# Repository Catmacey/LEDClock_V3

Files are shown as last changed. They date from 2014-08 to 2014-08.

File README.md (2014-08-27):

Circular LED Clock
==================

This is an digital LED "Analogue" clock using 60 dicrete LEDs in a circular pattern.
It's an old project built on two single sided boards. The boards are designed for easy home fabrication using the toner transfer technique.  The CPU board uses all DIP parts, the display board uses surface mount LEDs in 1206 package.

The MCU is a 18f2525 with a Maxim MAX6956 driving the LEDs and a Maxim DS1307 keeping time.

[More information is available on my blog.](http://catmacey.wordpress.com/projects/led-clock-project/led-clock-project-details/)

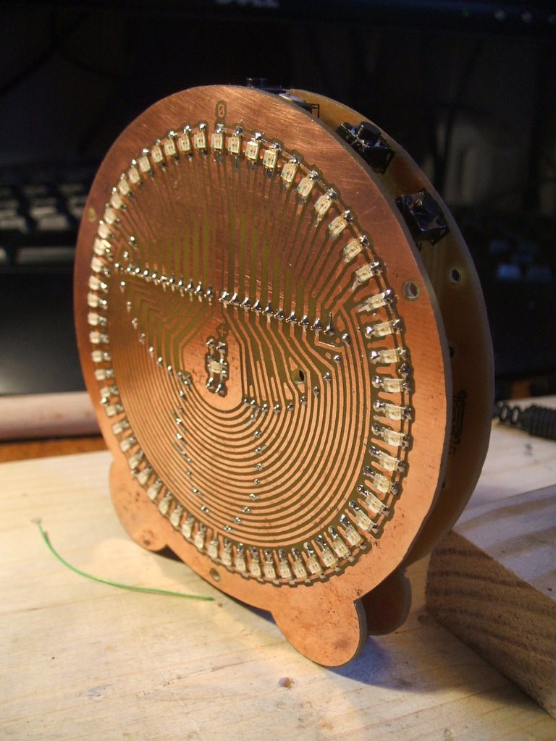
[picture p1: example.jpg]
My image


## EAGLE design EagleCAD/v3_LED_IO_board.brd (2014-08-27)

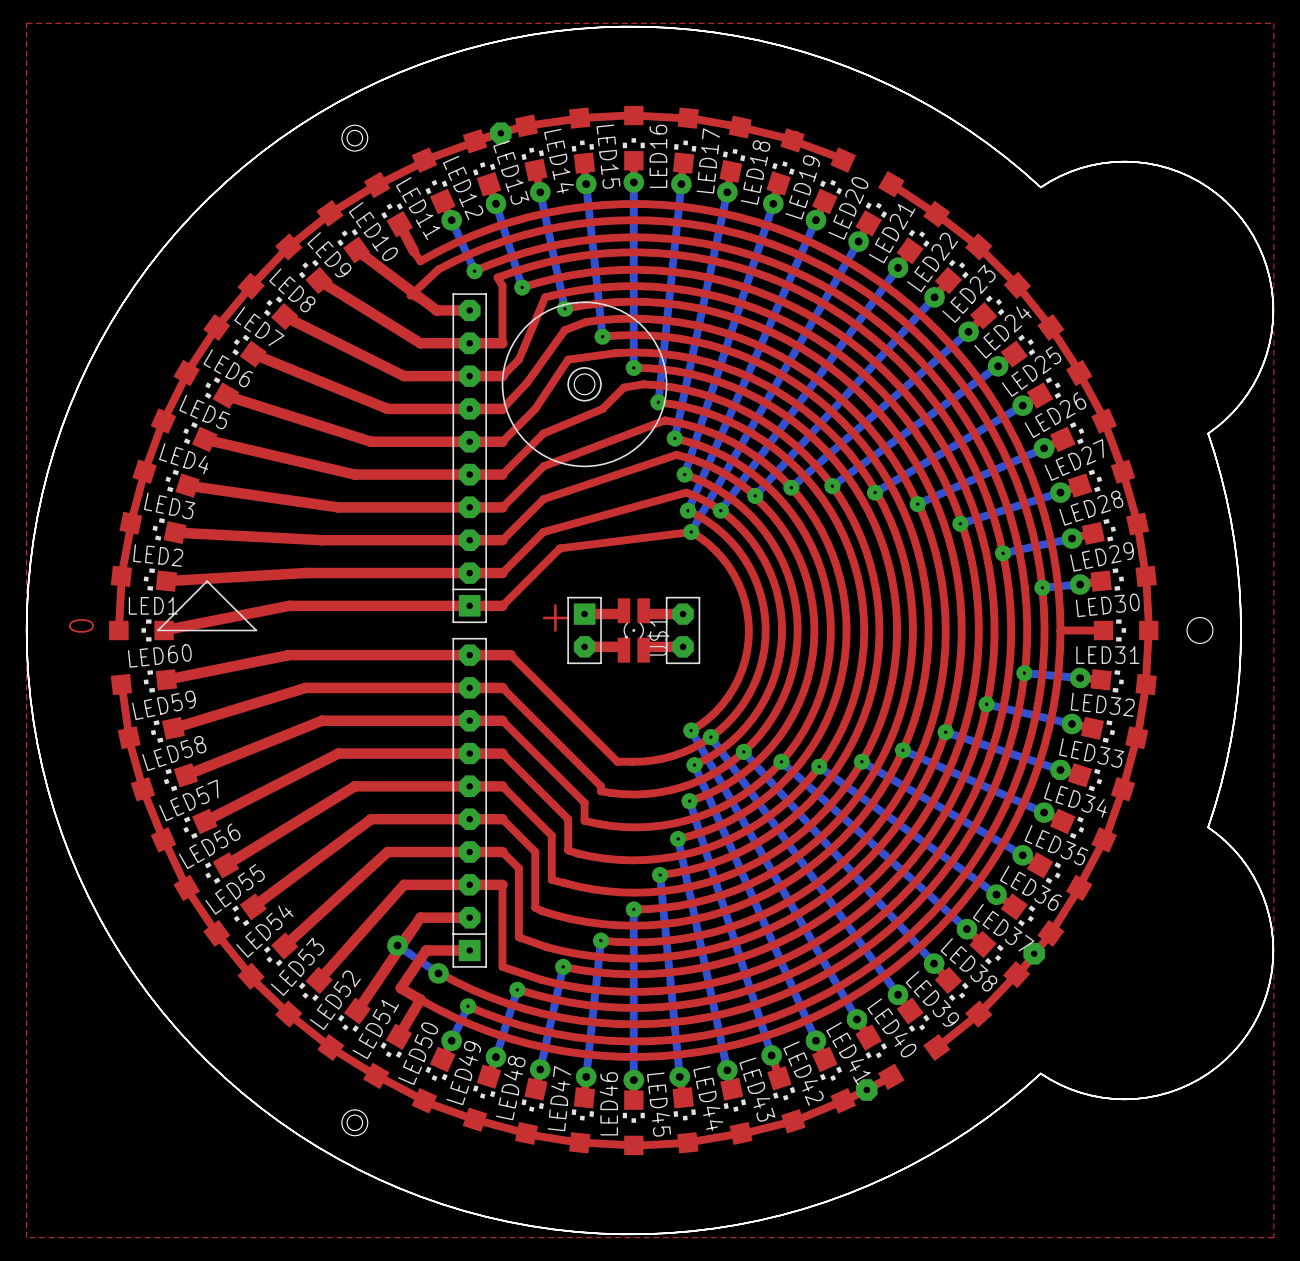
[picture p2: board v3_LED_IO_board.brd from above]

Board: 2 copper layers, 96.5 x 93.5 mm, 62 parts (0 on the bottom side), 27 nets.

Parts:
LED1, LED2, LED3, LED4, LED5, LED6, LED7, LED8, LED9, LED10, LED11, LED12, LED13, LED14, LED15, LED16, LED17, LED18, LED19, LED20, LED21, LED22, LED23, LED24, LED25, LED26, LED27, LED28, LED29, LED30, LED31, LED32, LED33, LED34, LED35, LED36, LED37, LED38, LED39, LED40, LED41, LED42, LED43, LED44, LED45, LED46, LED47, LED48, LED49, LED50, LED51, LED52, LED53, LED54, LED55, LED56, LED57, LED58, LED59, LED60: CHIPLED_1206
U$1: RGBLED; 1206_RGBLED
U$2: LEDCLOCK_FRONT

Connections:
+5V: U$1.A, U$2.+5V
LED6: LED6.C, LED26.C, LED46.C, U$2.JL6
unnamed: LED9.C, LED29.C, LED49.C, U$2.JL9
unnamed: LED1.A, LED2.A, LED3.A, LED4.A, LED5.A, LED6.A, LED7.A, LED8.A, LED9.A, LED10.A, LED11.A, LED12.A, LED13.A, LED14.A, LED15.A, LED16.A, LED17.A, LED18.A, LED19.A, LED20.A, U$2.BANK1
unnamed: LED1.C, LED21.C, LED41.C, U$2.JL1
unnamed: LED2.C, LED22.C, LED42.C, U$2.JL2
unnamed: LED3.C, LED23.C, LED43.C, U$2.JL3
unnamed: LED4.C, LED24.C, LED44.C, U$2.JL4
unnamed: LED5.C, LED25.C, LED45.C, U$2.JL5
unnamed: U$1.R, U$2.JIN1
unnamed: LED7.C, LED27.C, LED47.C, U$2.JL7
unnamed: LED19.C, LED39.C, LED59.C, U$2.JL19
unnamed: LED10.C, LED30.C, LED50.C, U$2.JL10
unnamed: U$1.B, U$2.JIN2
unnamed: U$1.G, U$2.JIN3
unnamed: LED8.C, LED28.C, LED48.C, U$2.JL8
unnamed: LED21.A, LED22.A, LED23.A, LED24.A, LED25.A, LED26.A, LED27.A, LED28.A, LED29.A, LED30.A, LED31.A, LED32.A, LED33.A, LED34.A, LED35.A, LED36.A, LED37.A, LED38.A, LED39.A, LED40.A, U$2.BANK2
unnamed: LED11.C, LED31.C, LED51.C, U$2.JL11
unnamed: LED12.C, LED32.C, LED52.C, U$2.JL12
unnamed: LED13.C, LED33.C, LED53.C, U$2.JL13
unnamed: LED14.C, LED34.C, LED54.C, U$2.JL14
unnamed: LED15.C, LED35.C, LED55.C, U$2.JL15
unnamed: LED17.C, LED37.C, LED57.C, U$2.JL17
unnamed: LED18.C, LED38.C, LED58.C, U$2.JL18
unnamed: LED20.C, LED40.C, LED60.C, U$2.JL20
unnamed: LED41.A, LED42.A, LED43.A, LED44.A, LED45.A, LED46.A, LED47.A, LED48.A, LED49.A, LED50.A, LED51.A, LED52.A, LED53.A, LED54.A, LED55.A, LED56.A, LED57.A, LED58.A, LED59.A, LED60.A, U$2.BANK3
unnamed: LED16.C, LED36.C, LED56.C, U$2.JL16

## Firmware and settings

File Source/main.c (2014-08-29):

/*
////////////////
	LED	analog clock
////////////////
*/

/*
////////////////
	Work log

*	Add some LEDs on portA to indicate status.
	Set Time : Set Alarm : Alarm active
!	Done : 19 Apr 07, also made time set & alarm set active only on delayed hold down.

!	Sort out reading/writing to the RTC.
	Might need to hard wire this to make I2C work ok.
	Also might need to slow down I2C, which might effect over all display
!	Done (most of) 22 Apr 07, reads for RTC, but doesn't set it yet. i2c at 100khz, seems ok.

!	Need to sort out writing time to RTC (dec2bcd)
!	Also need to sort out odd slownes of blinking for mins.
!	Compare alarm to current time.
!	Buzz or something for 10 mins
!	Just worked out why was having probs with RTC & GPIO on i2c bus
	Was due to the interrupt routine interrupting a main() i2c access
	Rememeber to either only i2c from isr or disable ints whilst i2c's in main()
!	Need to work out some sort of snooze mode for the alarm (hit any button other than alarm set)
	and wire up some sort of buzzer
!	Buzzer driven using PWM out on RB3.
!	Snooze and alarm to be working ok.  Alarm sounds for 25 mins with a 5 min snooze capability
!	Added LDR to RA0 to change global current of GPIO dependant on ambient light.
*	Want to re-write convertTime2light() to allow for...
	!	More realistic Hour display eg, use the LEDs inbetween the hours points to show like a real analog clock
	!	Simple animations on certain events.  Eg. every hours chase a dot around the clock or similar.
!	Buzzer swapped for active type, no need for pwm out still on rb3
!	Need to re-write main text (if) in alarm_test()
!	Indicator LED swapped for RGB LED to create multi colors
	PWM of RGB LED provided by using RA1
!	Animation capability added using effect_run() and associated funcs
!	MAX6956 individual LED current now used to balance the red/blue intensity.
!	PWM on RC0,1,2 now used to dim LEDs rather than global current of MAX6956

!	18 Nov 07
	Rewrite to use LAT for output rather than PORT
////////////////
*/


#include <p18cxxx.h>
#include <delays.h>
#include <usart.h>
#include <i2c.h>
#include <stdio.h>
#include <timers.h>
#include <adc.h>
#include <portb.h>
#pragma	config WDT = OFF

#define _SIM

#define	LoByte(i)	(	(unsigned	char)	i	)
#define	HiByte(i)	(	(unsigned	char)	(	((unsigned int)	i) >>	8) )
#define	MidByte(i)	(	(unsigned	char)	(	((unsigned short long) i)	>> 16) )
#define	TopByte(i)	(	(unsigned	char)	(	((unsigned long) i)	>> 24) )

//PortA
//outputs
#define	LDR						PORTAbits.RA0	//porta.0
#define	LED_PWM			LATAbits.LATA1	//porta.1
#define	ALARMOUT			LATAbits.LATA2	//porta.2
#define	LED_ALERT			LATAbits.LATA4	//active low (Green)
#define	LED_ALARM			LATAbits.LATA5	//active low (Red)
#define	LED_AMPM			LATAbits.LATA3	//active low (Blue)

//Port B
//inputs
#define	rtcin					PORTBbits.RB0	//Pulse input for RTC
#define	btn0					PORTBbits.RB1	//Alarm on/off/set
#define	btn1					PORTBbits.RB2	//Time set/run
#define	btn2					PORTBbits.RB3	//Snooze/sleep
#define	btn3					PORTBbits.RB4	//min inc
#define	btn4					PORTBbits.RB5	//hour
//outputs
#define	RB6	PORTBbits.RB6
#define	RB7	PORTBbits.RB7

//Masks for buttons
#define	BTN_ALARMSET		0b00100000
#define	BTN_TIMESET			0b00010000
#define	BTN_SNOOZE			0b00001000
#define	BTN_HOURADV		0b00000100
#define	BTN_MINADV			0b00000010
#define	DBOUNCEMASK		0b00111110 //only bother to count these pins in dbouncing
#define 	DLY_LONG				70	// A long delay for detecting a held down button (time and alarm set)
#define 	DLY_LONG_RST		75	// Ensures no repeat	
#define 	DLY_SHORT				33 	// A short delay for detecting a held down button (mins + hour advance)
#define	DLY_SHORT_RST	30	// Makes a nice repeat rate for advance
#define	LIGHTMAX				15	//max value for gbl_light
#define	LIGHTCEIL				512 //1024 - 512 //When light levels are below this level just use pwm of 0
#define	LIGHTDIV					(LIGHTCEIL / (LIGHTMAX+1))	//(1024 - 512) / 15

//Port C
#define	RC0		PORTCbits.RC0	//sector0 sel
#define	RC1		PORTCbits.RC1	//sector1 sel
#define	RC2		PORTCbits.RC2	//sector2 sel
#define	SCL		PORTCbits.RC3	//I2C clock,	PORTC	pin	3
#define	SDA		PORTCbits.RC4	//I2C data
#define	RC5		PORTCbits.RC5	
#define	TX		PORTCbits.RC6
#define	RX		PORTCbits.RC7

#define	MAX6956ADDR 0x80 //address of 6956 GPIO
#define	RTCADDR 0b11010000 //address of DS1307 RTC
#define	RTCLEN 3 //number of bytes to read from RTC (zero based)
#define	ALARMLIMIT 30 //max time for alarm
#define	SNOOZELIMIT 9 //max time for alarm

unsigned char gbl_ledBuffer_written; //used to flag that we have new data, not allowed to write until unset
unsigned char gbl_ledBuffer_bank; //[0|1] bank we are currently writing to. (isr reads other)
unsigned char	gbl_ledBuffer[2][3][3]; //gbl_ledBuffer :2 banks of 3 sectors of 3 bytes representing status of the	60 leds	(last	4	bits of	byte [x][3]	unused)
//unsigned short long gbl_effect.buffer[3]; //3 sectors of 24bits representing effects display(last 4 bits of byte [x][3]	unused)
struct{
		unsigned char sector; 	// Store which bank the effect is using. Or sometimes just a spare
		unsigned char ctr;			// Counter for effects so they can top themselves
		unsigned char mode;		// Effects mode
		unsigned char temp;		// Temp...
		union buffer_tmp{
			unsigned short long full;
			struct{
				unsigned char low;
				unsigned char mid;
				unsigned char high;
			};
		} buffer[3];
} gbl_effect;

rom	char sectorSelBits[] = {0x00,0x01,0x02};//Bank selects. AND this bits of port c (LATC)
rom	char sectorAddr[]	=	{0x4c,0x54,0x5c	};//addresses of GPOI ports 12-19,20-27,28-31

unsigned char	gbl_sector;						//used by isr to keep track of current sector
unsigned char	gbl_blinkOff_Min;			//should we blink the mins at all?
unsigned char	gbl_blinkStatus_Min;		//display mins (blink)
unsigned char gbl_blinkStatus_Sec;		//display seconds (blink), used to make seconds a quick pulse
unsigned char	gbl_display_secs;			//display seconds
unsigned char gbl_timeSelect;				//Set [0=time|1=alarm]
unsigned char	gbl_bRun;						//[run/set] time
unsigned char gbl_bTimeChanged;		//Set [1=time has changed]
unsigned char gbl_bAlarmSet;				//Set [1=alarm is armed]
unsigned char gbl_bAlarmSnd;				//Set [1=alarm is currently sounding!]
unsigned char gbl_bSnooze;					//Set [1=we are snoozing!]
unsigned char gbl_bPm;							//Set [0=am,1=pm]
unsigned char gbl_blinky;						//Used as a simple counter for blinking seconds and alarm
unsigned char	gbl_light;							//Light lever 0 - 24
unsigned char	gbl_PartialHour;				//Bool : 1 = show hours as partial, 0 = show hours as whole numbers

//Config words for GPIO {length (hex), start address (hex), data (hex)}
rom	char gpio_start_0[]			= {0x02,0x04,0b01000001};		//config byte
rom	char gpio_start_1[]			= {0x2,0x02,0x00001111};		//global current control : Unnecesary now we are using per seg current to balance brightness
rom	char gpio_start_2[]			= {0x08,0x09,0x00,0x00,0x00,0x00,0x00,0x00,0x00};	//config all ports as LED const cur	driver
//Current per segment
rom	char gpio_start_3[]			= {0x0c,0x16,0xf6,0xff,0x6f,0xff,0xff,0xf6,0xff,0x6f,0xff,0xff};
rom	char gpio_testModeOn[] 	= {0x02,0x07,0x01};
rom	char gpio_testModeOff[]	= {0x02,0x07,0x00};

unsigned char	gbl_temp[10];	//used as a temp buffer for communication

//Debounce stuff
#define	DBOUNCE_LEN 12//length of debounce buffer
unsigned char gbl_dbounce_buff[DBOUNCE_LEN];	//ring buffer for debouncing
unsigned char gbl_dbounce_idx;	//current byte to write
unsigned char gbl_status;	//current byte to write

//time holder : it's the same order as the RTC
union time_t{
	unsigned char arr[RTCLEN];
	struct{
		unsigned char second;
		unsigned char minute;
		unsigned char hour;
/*
		unsigned char day;
		unsigned char date;
		unsigned char month;
		unsigned char year;
*/
	};
} times[3];
//Indexes of time holders
#define	TNOW 0 //now
#define	TALMON 1 //Alarm on
#define	TSNOOZE 2 //Alarm sleep

#define	SEC		0 //position in time_t.arr
#define	MIN		1 //position in time_t.arr
#define	HOUR	2 //position in time_t.arr

//func prototypes
void boot_up(	void );
void gpio_init(void);
void rtc_init(void);
void convertTime2light();
void effect_run();
void set_dbounce();
void time_inc(union time_t *theTime, unsigned char part, unsigned char amount);
void effect_next();
void gpio_readConfig(unsigned char addr, unsigned char length);
signed char	I2C_sendRomStr(unsigned	char addr, unsigned	rom	char *wrptr	);
signed char	gpio_drawSector(unsigned char sector);
signed char	readRTC();
signed char	setRTC();
signed char	alarm_storeTime();
unsigned char	time_dec(unsigned	char part,unsigned char	amount);
unsigned char get_dbounce();
unsigned char bcd2dec(unsigned char bcd);
unsigned char dec2bcd(unsigned char dec);
unsigned int timeDiff(unsigned char timeIdx1, unsigned char timeIdx2);


void timer_isr (void);
#pragma	code low_vector=0x18
void
low_interrupt	(void){
	_asm GOTO	timer_isr	_endasm
}
#pragma	code

#pragma	interruptlow timer_isr
void timer_isr (void){
	//int
	signed char rtn;
	unsigned char tmp;
	
	if(INTCONbits.INT0IF){
		//RTC seconds ticker
		time_inc(&times[TNOW],SEC,1);
		gbl_blinkStatus_Min = !gbl_blinkStatus_Min;
		gbl_bTimeChanged = 1;//flag that time has changed (alarm test uses this)
		INTCONbits.INT0IF = 0;	//reset int
	}

	tmp = gbl_sector;
	
	if(INTCONbits.TMR0IF){
		//Timer 0 int
		
		//PWM of Indicator LEDS. 6bit period (63), max duty of 16
		if(
			((gbl_blinky & 0b00111111) <= gbl_light)
			||
			gbl_bAlarmSnd
		){
			//ON
			//pwm for center led
			LED_PWM = 1;
		}else{
			//OFF
			LED_PWM = 0;
		}

		//PWM of Sectors. 5bit period (31), max duty of 16
		if(
			((gbl_blinky & 0b00011111) <= gbl_light)
			||
			gbl_bAlarmSnd
		){
			//ON
			//pwm for sectors already set by code below
		}else{
			//OFF
			LATC &= 0b11111000;		
		}

		//de-Bounce inputs (portB). Every 32th int
		if((gbl_blinky & (unsigned char) 0b00000111) == (unsigned char) 0b00000111){
			set_dbounce();
		}
		
		//Write to MAX6956
		if((gbl_blinky & (unsigned char) 0b00011111) == (unsigned char) 0b00011111){
			//every 16th int			
			if(gbl_sector > (unsigned char) 2){
				gbl_sector = 0;
				if(gbl_ledBuffer_written){
					//new data on other buffer so toggle it, but only after all 3 sectors have been displayed
					if(gbl_ledBuffer_bank) gbl_ledBuffer_bank = 0;
					else gbl_ledBuffer_bank = 1;
					gbl_ledBuffer_written = 0;//flag main() that it can write to buffer again.
				}//if
			}//if
	
			rtn = gpio_drawSector(gbl_sector);	// Write to the GPIO
			if(rtn) fprintf	(_H_USART, "(%#i) ",rtn); //error writing
			//sector counter
			gbl_sector++;
		}
		gbl_blinky++;
		INTCONbits.TMR0IF	=	0;	//reset	timer 0
	}
}//func

void alarm_updateOff(){
	//copies alarm time to alarm off time + 15 mins
	fprintf(_H_USART, "\r\nalarm_updateOff(");
	times[TSNOOZE] = times[TALMON]; //snooze defaults to alarm on
	fprintf(_H_USART, "Snooze %.2u:%.2u:%.2u)\r\n",times[TSNOOZE].hour,times[TSNOOZE].minute,0);
}

void alarm_setSnooze(){
	//set snooze time times[TSNOOZE] and flag
	fprintf(_H_USART, "\r\nalarm_setSnooze(");
	if(gbl_bAlarmSnd){
		//set snooze time
		gbl_bSnooze = 1;
		times[TSNOOZE] = times[TNOW];
		time_inc(&times[TSNOOZE],MIN,SNOOZELIMIT);
		fprintf(_H_USART, "%.2u:%.2u:%.2u",times[TSNOOZE].hour,times[TSNOOZE].minute,times[TSNOOZE].second);
	}else{
		//not alarm sounding, no point
		gbl_bSnooze = 0;
		fprintf(_H_USART, "nada");
	}
	fprintf(_H_USART, ")\r\n");
}

/*
	calculates the difference between time 1 and time 2 (index's supplied)
	timeIdx1 = now, timeIdx2 = then
	Returns result in mins always positive cos could be tomorrow (unsigned int) 
*/
unsigned int timeDiff(unsigned char timeIdx1, unsigned char timeIdx2){
	unsigned int timeDiff;
	unsigned int timeNow;
	unsigned int timeThen;
	timeNow 		= ((unsigned int) times[timeIdx1].hour * 60) + times[timeIdx1].minute; //minutes
	timeThen 	= ((unsigned int) times[timeIdx2].hour * 60) + times[timeIdx2].minute; //minutes
	if(timeNow <= timeThen){
		//then is in the future within the same day.
		timeDiff = timeThen - timeNow;
	}else{
		//then is in the past, so could be tommorrow.
		timeDiff = timeThen + 1440 - timeNow;
	}//if
	//fprintf	(_H_USART, "Now[%#.1u] %#.2u:%#.2u (%u), then[%#.1u] %#.2u:%#.2u (%u), diff:%#.4u\r\n", timeIdx1, times[timeIdx1].hour, times[timeIdx1].minute, timeNow, timeIdx2, times[timeIdx2].hour, times[timeIdx2].minute, timeThen, timeDiff);
	return timeDiff;
}


void alarm_test(){
	//checks current time against alarm
	/*
	fprintf	(_H_USART, "\r\nTest alarm. %b\r\n",gbl_bAlarmSet);
	fprintf	(_H_USART, "Time : %#.2u:%#.2u\r\n", times[TNOW].hour,times[TNOW].minute);
	fprintf	(_H_USART, "Alon : %#.2u:%#.2u\r\n", times[TALMON].hour,times[TALMON].minute);
	fprintf	(_H_USART, "Snz : %#.2u:%#.2u\r\n", times[TSNOOZE].hour,times[TSNOOZE].minute);
	*/
	if(
		gbl_bAlarmSet
		&
		timeDiff((unsigned char) TALMON,(unsigned char) TNOW) < (unsigned char) ALARMLIMIT //diff between now and alarm tigger <= ALARMLIMIT
	){
		gbl_bAlarmSnd = 1; //Alarm sounding (or at least it might be)
		if(timeDiff((unsigned char) TSNOOZE, (unsigned char) TNOW) < (unsigned char) SNOOZELIMIT){
			//within the alarm time and not snoozing, sound alarm
			fprintf	(_H_USART, "\r\nAlarm!\r\n");
			if(times[TNOW].second & 0b00000001) {
				ALARMOUT = 1;  //sound alarm
			}else{
				ALARMOUT = 0;  //un-sound alarm
			}//if
		}//if
	}else{
		gbl_bAlarmSnd = 0;
		ALARMOUT = 0;  //un-sound alarm
	}//if
}//func

void gpio_setGlobalCurrent(unsigned char current){
	unsigned char	rtn;
	//fprintf(_H_USART, "\r\ngpio_setGlobalCurrent(");
	INTCONbits.GIE = 0; //disable ints for i2c write
	rtn = EEByteWrite(MAX6956ADDR,0x02,current & 0b00001111);
	INTCONbits.GIE = 1;
	//fprintf(_H_USART, "%u : %.8b)\r\n",current,current);
}// end gpio_init(void)


void gpio_setSegCurrent(unsigned char current){
	unsigned char	rtn;
	unsigned char idx ;
	unsigned char cur[16];
	unsigned char tmp;
	current &= 0b00001111; //truncate to < 16
	tmp = current << 4;
	for(idx=0;idx < 10;idx++){
		cur[idx] = 0xff;
		switch (idx){
			case 0 : 
			case 5 :
				cur[idx] = current | (cur[idx] & 0b11110000);
				break;
			case 2 :
			case 7 :
				cur[idx] = tmp | (cur[idx] & 0b00001111);
				break;
			default :
				cur[idx] = 0xff;
		}//switch
		fprintf(_H_USART, "\r\n%2.2x",cur[idx]);
	}//for
	fprintf(_H_USART, "\r\n gpio_setSegCurrent(");
	INTCONbits.GIE = 0; //disable ints for i2c write
	//rtn = I2C_sendRomStr(MAX6956ADDR,gpio_start_3);
	rtn = EEPageWrite(MAX6956ADDR,0x16,cur);
	INTCONbits.GIE = 1;
	fprintf(_H_USART, "%2.2x : %u)\r\n",tmp,rtn);
}// end gpio_init(void)

void main(){
	unsigned char	ctr				= 0;	//gp counter
	unsigned char	tmp				= 0;	//temp var
	unsigned char prv_status	= 0b00000000; //toggle watcher
	unsigned char chg_status	= 0b00000000; //toggle watcher
	unsigned char	btnWait0		= 0;	//wait before btnRepeat
	unsigned char	btnWait1		= 0;	//wait before btnRepeat
	unsigned char	btnWait2		= 0;	//wait before btnRepeat
	unsigned char	btnWait3		= 0;	//wait before btnRepeat
	unsigned char	btnWait4		= 0;	//wait before btnRepeat
	signed 		char	rtn				= 0;	//temp var
	unsigned char bDispSecs	= 0; //hold status of gbl_display_secs whilst we temporaily turn it off
	unsigned char	gotADC		=	0;	//have an ADC value to read
	unsigned int 	light				=	0;	//ADC value
	
	boot_up();	//inti the peripherals
	Delay1KTCYx(10);
	gpio_init();	//init the GPIO

	ctr										=	0;// general purpose counter;
	tmp										=	0;
	gbl_bRun								= 1; //Run?
	gbl_timeSelect					= 0; //work with current time times[TNOW]
	gbl_blinkOff_Min					= 0;//allow mins to blink
	gbl_blinkStatus_Min			= 1;//mins currently displayed
	gbl_blinkStatus_Sec			=	1;//secs currently on (if gbl_display_secs == 1)
	gbl_ledBuffer_bank				= 0;//start using bank 0;
	gbl_display_secs					= 1;//display seconds
	gbl_bAlarmSet						= 0;//is the alarm set?
	gbl_ledBuffer_written			= 0;//convertTime2light sets high when new data avalable. isr notices and flips buffer, then sets low. cT2L cannot write more until low again.
	gbl_bAlarmSnd					= 0;//alarm not sounding
	gbl_bSnooze						= 0;//not snoozing
	gbl_PartialHour					= 1;//show partial hours
	gbl_effect.sector					=	0;//start sector for global effects
	while(ctr<3){
		//writeoutput	to buffer
		gbl_effect.buffer[ctr].full = 0;
		gbl_effect.buffer[ctr].full = 0;
		gbl_effect.buffer[ctr].full = 0;
		ctr++;
	}//for
	gbl_effect.mode		= 0; //
	gbl_effect.ctr 		= 0; //dev

	
	//All LED's off
	LED_ALERT				= 1;
	LED_ALARM				= 1;
	LED_AMPM				= 1;
	Delay1KTCYx(0);

	rtn = readRTC();//read RTC current time and alarmtime
	//fprintf	(_H_USART, "\r\nTime  : %#.2u:%#.2u:%#.2u\r\n", times[TNOW].hour,times[TNOW].minute,times[TNOW].second);
	//fprintf	(_H_USART, "\r\nAlarm : %#.2u:%#.2u:%#.2u\r\n", times[TALMON].hour,times[TALMON].minute,times[TALMON].second);
	alarm_updateOff();//update alarm off time

	INTCONbits.GIE 					= 1;	//Start ints

	while(1){
		prv_status = gbl_status; //Store previous status
		gbl_status = get_dbounce();
		chg_status = gbl_status ^ prv_status; //xor current and prev status to flag changes

		//tmp = ctr & 0b00010000;
		//fprintf	(_H_USART, "\r\n%#.3u : %#.3u : %#.3u\r\n",gbl_bAlarmSet,gbl_bAlarmSnd,tmp);

		if(gbl_bRun){
			//LED Status whilst time is running
			//alarm led
			if(gbl_bAlarmSet)	LED_ALARM = 0; //light alarm set LED
			else							LED_ALARM = 1; //led is active low
	
			//alert LED
			if(gbl_bAlarmSnd){
				if((ctr & (unsigned char) 0b00100000) > (unsigned char) 0) LED_ALERT = !LED_ALERT;//blink alarm led if alarm is sounding
			}else LED_ALERT = 1;
		}

		//pm led : Always processed
		if(gbl_bPm) 				LED_AMPM = 0; //light AM/PM LED
		else 							LED_AMPM = 1; //led is active low	
		
		//gbl_blinkStatus_Sec = 0;
		
		if(gbl_bTimeChanged){
			//only check if time has changed. ie every second, but not so time critical as to need an interrupt
			alarm_test();
			gbl_blinkStatus_Sec = 1;
			if(gbl_bAlarmSnd){
				//max brightnes, alarm is sounding
				gbl_light = 24;
				//Cycle effects every other second
				if((times[TNOW].second & 0b00000111) == 0b00000111){
					gbl_effect.ctr 	= 2;
					gbl_effect.mode++;
				}
			}else{
				if(times[TNOW].minute == 0 & times[TNOW].second == 0){
					//spin effect on the hour
					gbl_effect.ctr 	= 1;
					gbl_effect.mode = 3;
				}
				if(!BusyADC()){
					if(!gotADC){
						//rintf	(_H_USART, "Start ADC\r\n");
						ConvertADC(); // Start conversion if not busy
						gotADC = 1;
					}else{
						light = ReadADC(); // Read result
						/*
							Assume range of 0(light) to 1024(dark)
							We have a cut off point of LIGHTCEIL that sets where we start to increase LED brightness
							This allows us to tweak things to ensure our LEDs are not too bright in dimly lit bedrooms.
						*/
						if(light < LIGHTCEIL){
							//Start to increase brightness
							gbl_light = LIGHTMAX - (unsigned char) (light / LIGHTDIV); //end up with value between 0 and 15			
							//fprintf	(_H_USART, "\r\n %2.1u - ( %4.1i / %2.1u ) = %2.1u ",LIGHTMAX, light, LIGHTDIV, gbl_light);
						}else{
							//Minimum brightness
							gbl_light = 0;
						}
						//fprintf(_H_USART, "\r\nL%4.4i:%2.2u",light, gbl_light);
						gotADC = 0;
					}//if
				}//if
			}
			
			//set global brightness once a second
			gbl_bTimeChanged = 0;
		}
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
